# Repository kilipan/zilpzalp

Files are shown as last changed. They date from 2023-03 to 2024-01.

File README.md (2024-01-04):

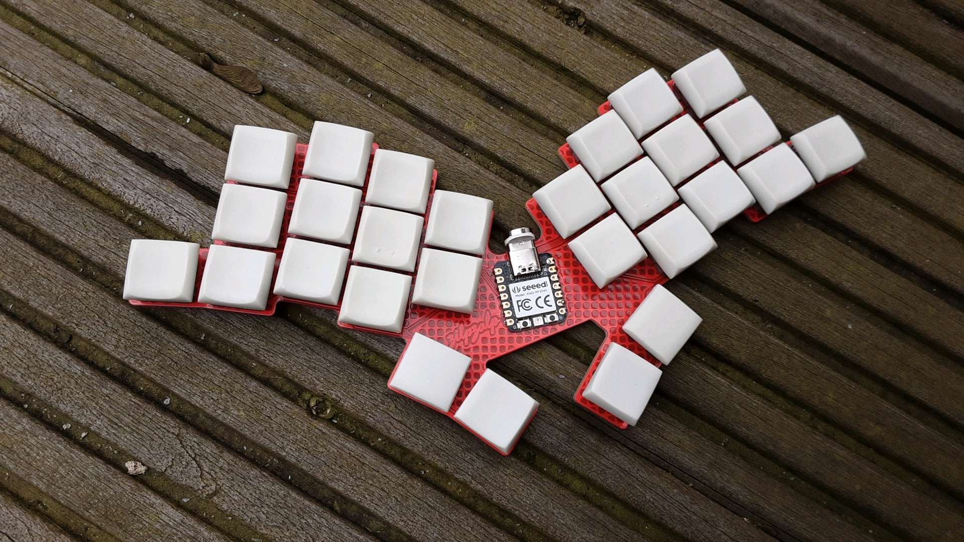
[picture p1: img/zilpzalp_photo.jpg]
zilpzalp


# zilpzalp
A wonky 28-key, column-staggered, unibody-split keyboard made with fantastic FOSS software: [ergogen](https://github.com/ergogen/ergogen) and [KiCad](https://www.kicad.org/).

For buying ready-to-assemble kits, consider [keeb.supply](https://keeb.supply/products/zilpzalp)! They share part of the profits made by selling zilpzalp with me!

Four versions for choc switches are available:
- the choc version with support for optional hotswap sockets and slightly extended edgecuts to acommodate the extra space required by the socket (in the [pcb](https://github.com/kilipan/zilpzalp/tree/main/pcb) directory)
- the cfx version with different spacing, making the zilpzalp almost 1.5 cm smaller horizontally (in the [pcb_cfx_spacing](https://github.com/kilipan/zilpzalp/tree/main/pcb_cfx_spacing) directory)
- the default-spacing solder-only version with tighter edge cuts (in the [pcb_solder_only](https://github.com/kilipan/zilpzalp/tree/main/pcb_solder_only) directory)
- the minimal-choc-spacing solder-only version with the tightest spacing that choc V1 switches allow for (in the [pcb_minimal_choc](https://github.com/kilipan/zilpzalp/tree/main/pcb_minimal_choc) directory)  
  **Note:** You will have to procure minimal-spacing keycaps. I am not aware of any commercial solution. Recommendation: [Philadelphia Minimalist](https://github.com/pseudoku/PseudoMakeMeKeyCapProfiles/blob/master/Philadelphia_Minimalist.scad) by [Pseudoku](https://github.com/pseudoku)

One version for MX, KS-27, and KS-33 switches is available:
- this version has default MX-spacing and features a hybrid switch-footprint for hotswap-only MX and solder-only KS-27/33 (in the [pcb_mx_spacing](https://github.com/kilipan/zilpzalp/tree/main/pcb_mx_spacing) directory)

**Warning:** The solder-only default choc-spacing version has not been tested yet!

Some example keymaps for getting an idea of how zilpzalp may be used can be found in the [`example_keymaps` directory](https://github.com/kilipan/zilpzalp/tree/main/example_keymaps).

## BOM
- 1 pcb
- 1 Seeed XIAO compatible controller, like e.g. [Miao](https://github.com/kilipan/miao)
- 14 sot23 diodes (common cathode)
- optional (for hot swap versions only): 28 hot swap sockets  
  (choc or mx depending on pcb version)
- 28 kailh choc low profile switches
- 28 fitting keycaps (pay special attention here when building the cfx or minimal-spacing version!)

## Firmware
I personally use and recommend [ZMK firmware](https://github.com/kilipan/zmk-config-zilpzalp) which is tested and confirmed-functional for the Seeed XIAO RP2040 and the Seeed XIAO BLE controllers.  
Check out [FAK firmware](https://github.com/semickolon/fak) if you're planning to use the Miao!  
[QMK firmware](https://github.com/kilipan/qmk-config-zilpzalp) for the Seeed XIAO RP2040 is also available.

## Inspiration
- all the fantastic keyboards, knowledge, and help by [GEIST](https://github.com/GEIGEIGEIST/), [Freya](https://linktr.ee/freya_irl), [Bob](https://github.com/GroooveBob), and the wonderful Clacktales keyboard community
- the [hummingbird](https://github.com/PJE66/hummingbird) keyboard and the [rufous](https://github.com/jcmkk3/trochilidae#rufous) variation
- the [aptmak](https://github.com/apsu/aptmak) keymap

<p align="center">

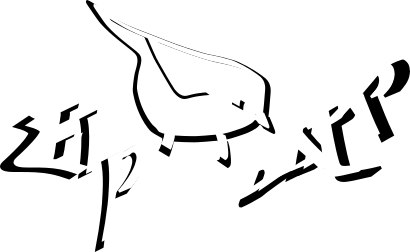
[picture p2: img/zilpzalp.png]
zilpzalp


</p>

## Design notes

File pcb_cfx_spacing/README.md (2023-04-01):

# CFX VERSION
**Warning:** This pcb version uses tighter spacing between switches and **most common keycaps do not fit!**  
  
This pcb was designed for Chosfox's Chocfox (a.k.a. CFX) keycaps' spacing in mind. That means only **square** keycaps with 16.5 mm by 16.5 mm (or smaller) will fit.

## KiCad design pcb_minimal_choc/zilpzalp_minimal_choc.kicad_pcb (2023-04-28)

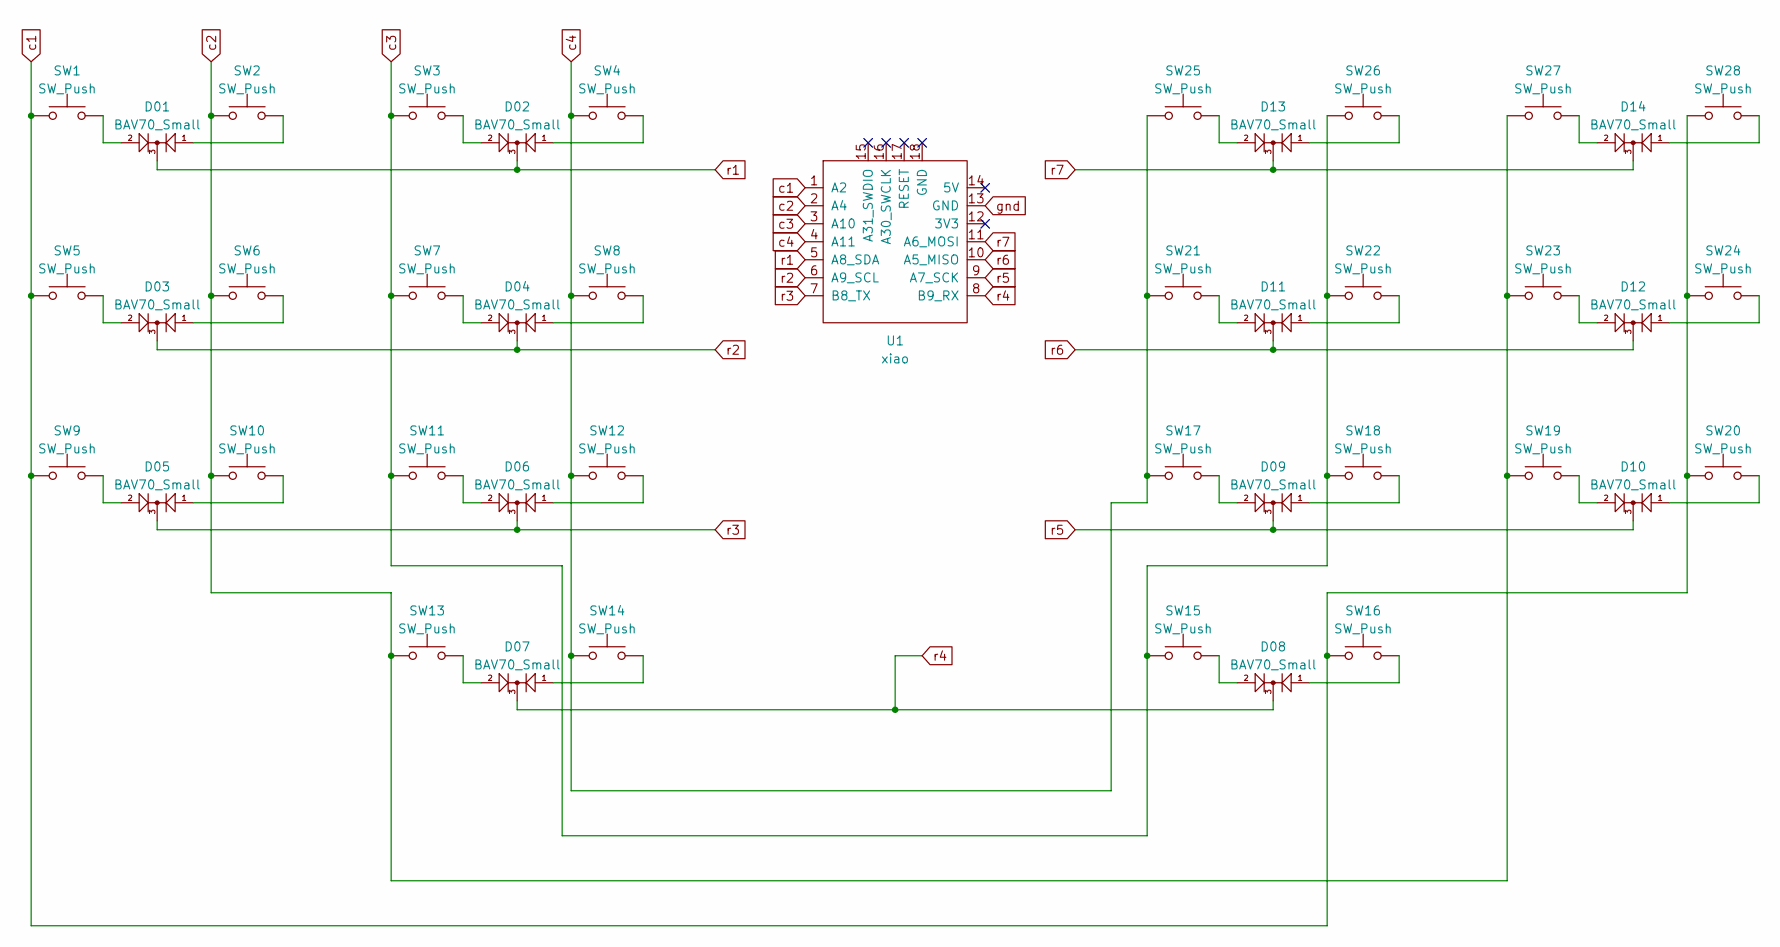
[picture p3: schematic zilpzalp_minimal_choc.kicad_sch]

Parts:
D01, D02, D03, D04, D05, D06, D07, D08, D09, D10, D11, D12, D13, D14: BAV70_Small; SOT-23_Handsoldering
SW1, SW2, SW3, SW4, SW5, SW6, SW7, SW8, SW9, SW10, SW11, SW12, SW13, SW14, SW15, SW16, SW17, SW18, SW19, SW20, SW21, SW22, SW23, SW24, SW25, SW26, SW27, SW28: SW_Push; SW_Kailh-PG1350-1u-NoLED
U1: xiao; xiao-tht

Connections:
unnamed: D01.1 (A1), SW2.2
unnamed: D01.2 (A2), SW1.2
unnamed: D02.1 (A1), SW4.2
unnamed: D02.2 (A2), SW3.2
unnamed: D03.1 (A1), SW6.2
unnamed: D03.2 (A2), SW5.2
unnamed: D04.1 (A1), SW8.2
unnamed: D04.2 (A2), SW7.2
unnamed: D05.1 (A1), SW10.2
unnamed: D05.2 (A2), SW9.2
unnamed: D06.1 (A1), SW12.2
unnamed: D06.2 (A2), SW11.2
unnamed: D07.1 (A1), SW14.2
unnamed: D07.2 (A2), SW13.2
unnamed: D08.1 (A1), SW16.2
unnamed: D08.2 (A2), SW15.2
unnamed: D09.1 (A1), SW18.2
unnamed: D09.2 (A2), SW17.2
unnamed: D10.1 (A1), SW20.2
unnamed: D10.2 (A2), SW19.2
unnamed: D11.1 (A1), SW22.2
unnamed: D11.2 (A2), SW21.2
unnamed: D12.1 (A1), SW24.2
unnamed: D12.2 (A2), SW23.2
unnamed: D13.1 (A1), SW26.2
unnamed: D13.2 (A2), SW25.2
unnamed: D14.1 (A1), SW28.2
unnamed: D14.2 (A2), SW27.2
c1: SW1.1, SW5.1, SW9.1, SW16.1, SW20.1, SW24.1, SW28.1, U1.1 (A2)
c2: SW2.1, SW6.1, SW10.1, SW13.1, SW19.1, SW23.1, SW27.1, U1.2 (A4)
c3: SW3.1, SW7.1, SW11.1, SW15.1, SW18.1, SW22.1, SW26.1, U1.3 (A10)
c4: SW4.1, SW8.1, SW12.1, SW14.1, SW17.1, SW21.1, SW25.1, U1.4 (A11)
gnd: U1.13 (GND)
r1: D01.3 (K), D02.3 (K), U1.5 (A8_SDA)
r2: D03.3 (K), D04.3 (K), U1.6 (A9_SCL)
r3: D05.3 (K), D06.3 (K), U1.7 (B8_TX)
r4: D07.3 (K), D08.3 (K), U1.8 (B9_RX)
r5: D09.3 (K), D10.3 (K), U1.9 (A7_SCK)
r6: D11.3 (K), D12.3 (K), U1.10 (A5_MISO)
r7: D13.3 (K), D14.3 (K), U1.11 (A6_MOSI)

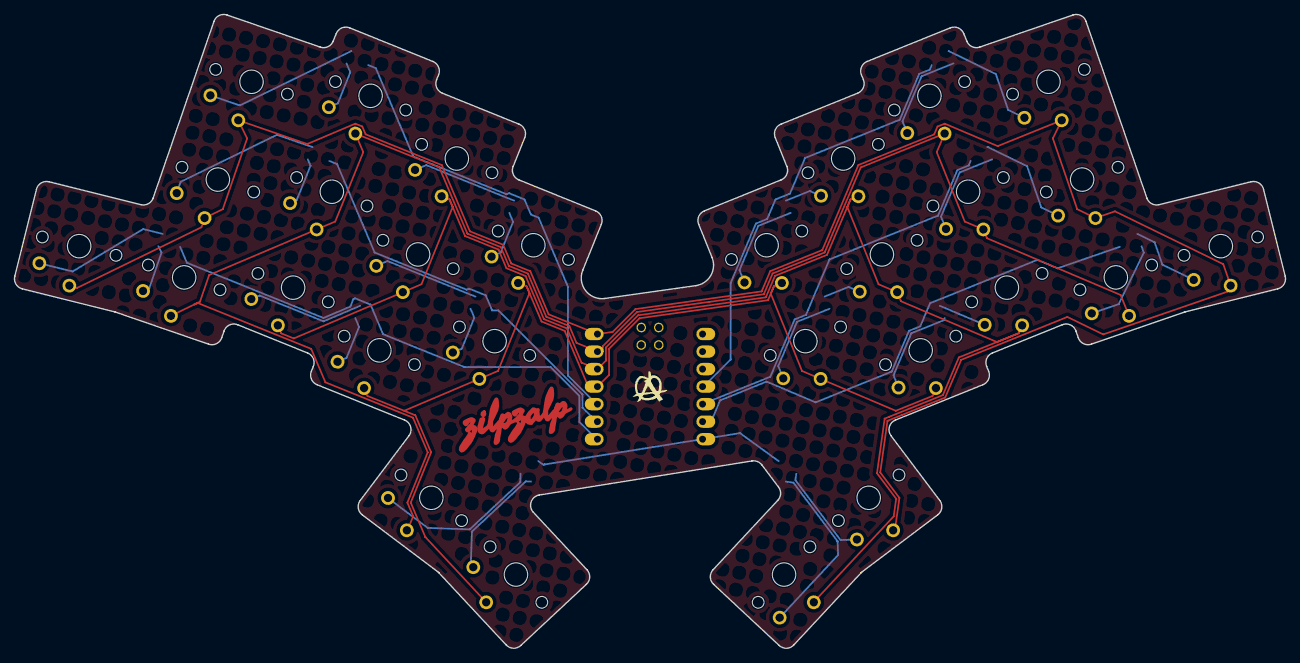
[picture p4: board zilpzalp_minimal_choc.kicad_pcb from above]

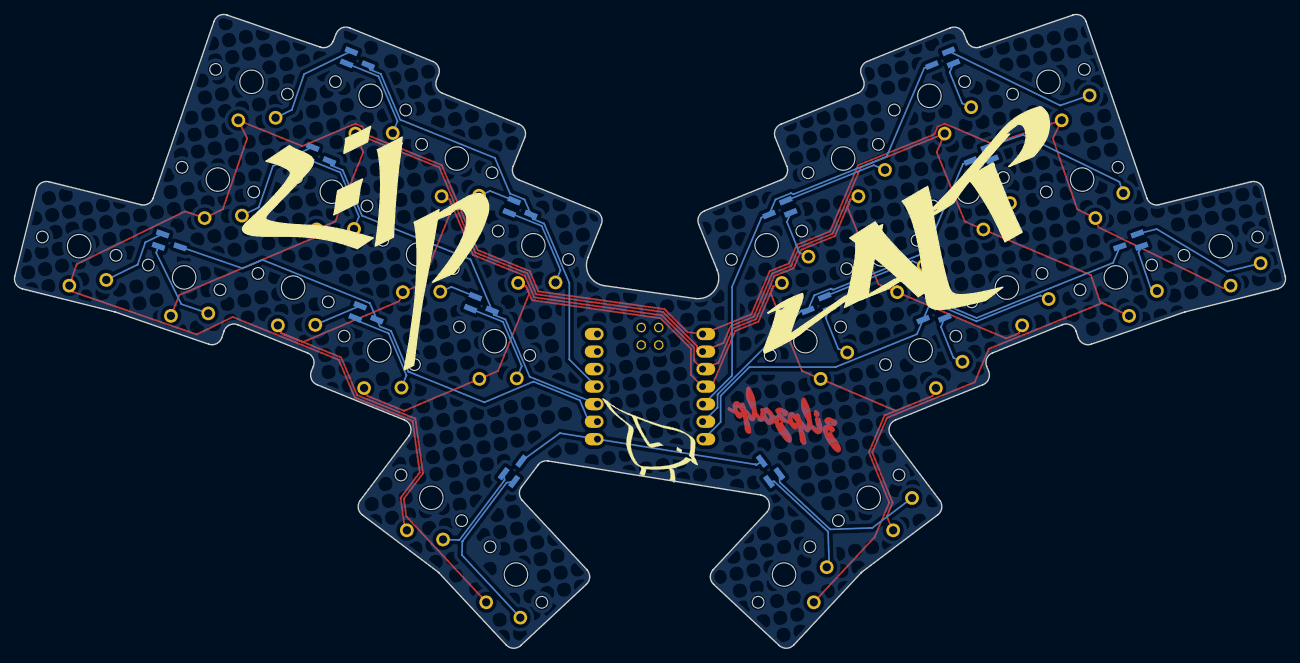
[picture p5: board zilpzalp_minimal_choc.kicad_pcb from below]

Board: 2 copper layers, 184.3 x 91.9 mm, 43 parts (14 on the bottom side), 39 nets.

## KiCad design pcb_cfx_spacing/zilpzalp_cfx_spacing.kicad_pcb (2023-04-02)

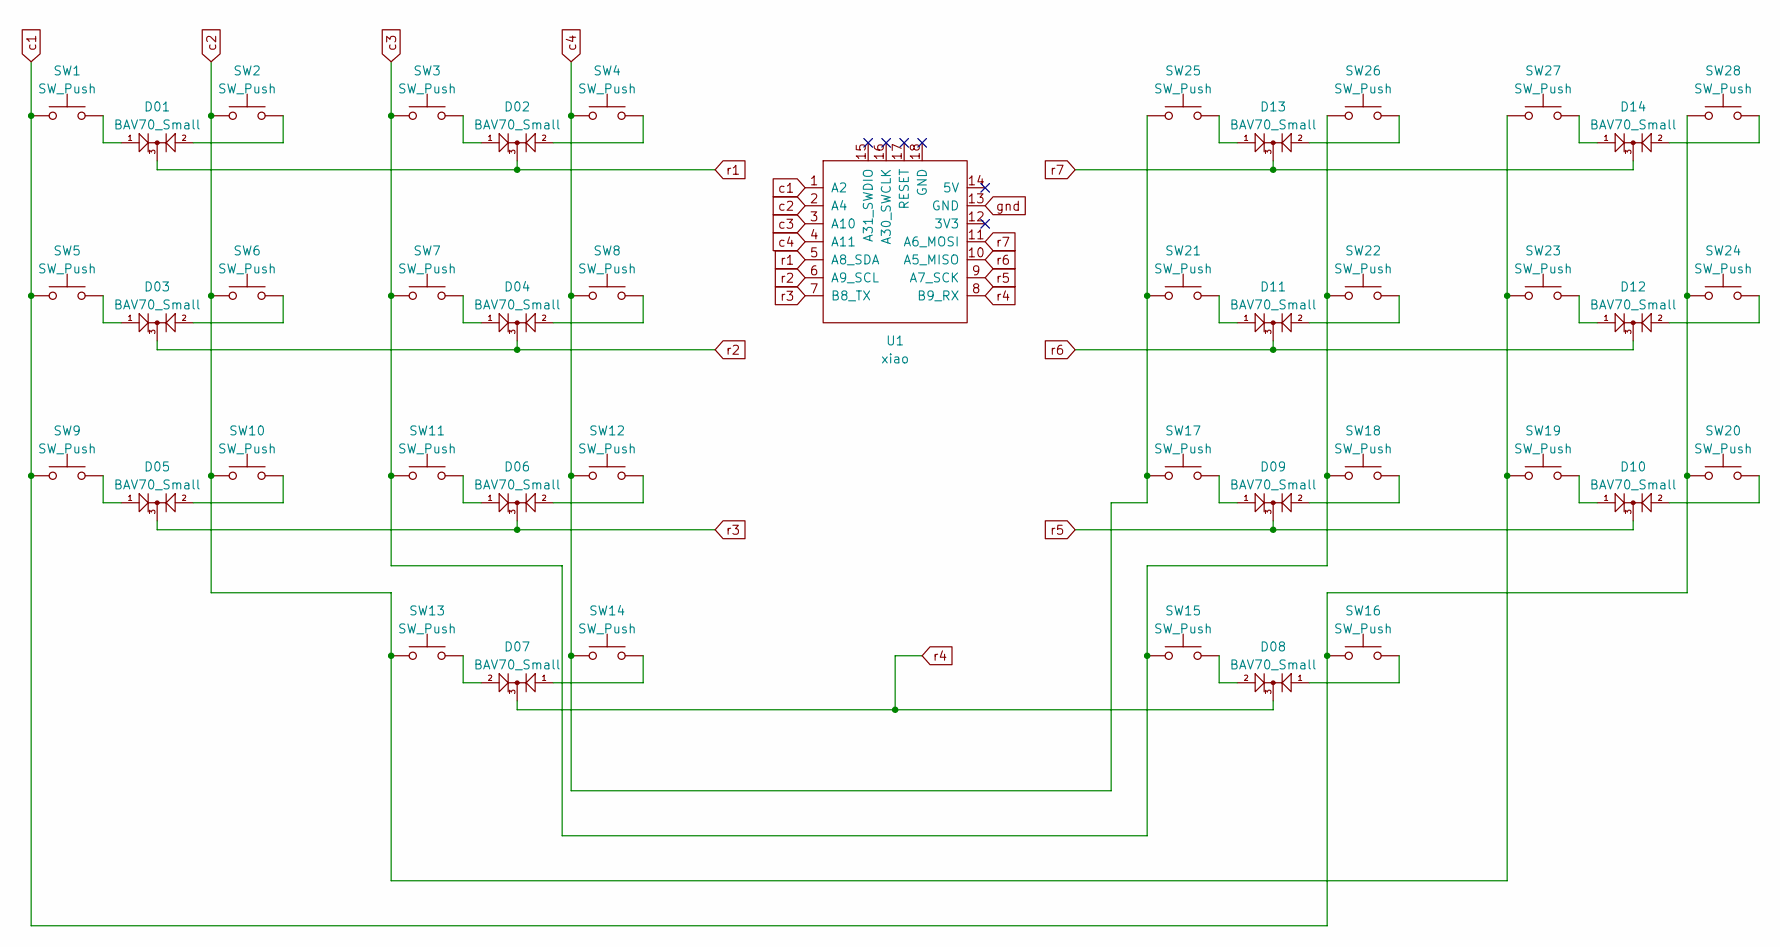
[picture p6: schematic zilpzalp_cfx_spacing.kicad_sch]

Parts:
D01, D02, D03, D04, D05, D06, D07, D08, D09, D10, D11, D12, D13, D14: BAV70_Small; SOT-23_Handsoldering
SW1, SW2, SW3, SW4, SW5, SW6, SW7, SW8, SW9, SW10, SW11, SW12, SW13, SW14, SW15, SW16, SW17, SW18, SW19, SW20, SW21, SW22, SW23, SW24, SW25, SW26, SW27, SW28: SW_Push; SW_Kailh_choc_hs_plus_solder_no_silk
U1: xiao; xiao-tht

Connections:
unnamed: D01.1 (A1), SW1.2
unnamed: D01.2 (A2), SW2.2
unnamed: D02.1 (A1), SW3.2
unnamed: D02.2 (A2), SW4.2
unnamed: D03.1 (A1), SW5.2
unnamed: D03.2 (A2), SW6.2
unnamed: D04.1 (A1), SW7.2
unnamed: D04.2 (A2), SW8.2
unnamed: D05.1 (A1), SW9.2
unnamed: D05.2 (A2), SW10.2
unnamed: D06.1 (A1), SW11.2
unnamed: D06.2 (A2), SW12.2
unnamed: D07.1 (A1), SW14.2
unnamed: D07.2 (A2), SW13.2
unnamed: D08.1 (A1), SW16.2
unnamed: D08.2 (A2), SW15.2
unnamed: D09.1 (A1), SW17.2
unnamed: D09.2 (A2), SW18.2
unnamed: D10.1 (A1), SW19.2
unnamed: D10.2 (A2), SW20.2
unnamed: D11.1 (A1), SW21.2
unnamed: D11.2 (A2), SW22.2
unnamed: D12.1 (A1), SW23.2
unnamed: D12.2 (A2), SW24.2
unnamed: D13.1 (A1), SW25.2
unnamed: D13.2 (A2), SW26.2
unnamed: D14.1 (A1), SW27.2
unnamed: D14.2 (A2), SW28.2
c1: SW1.1, SW5.1, SW9.1, SW16.1, SW20.1, SW24.1, SW28.1, U1.1 (A2)
c2: SW2.1, SW6.1, SW10.1, SW13.1, SW19.1, SW23.1, SW27.1, U1.2 (A4)
c3: SW3.1, SW7.1, SW11.1, SW15.1, SW18.1, SW22.1, SW26.1, U1.3 (A10)
c4: SW4.1, SW8.1, SW12.1, SW14.1, SW17.1, SW21.1, SW25.1, U1.4 (A11)
gnd: U1.13 (GND)
r1: D01.3 (K), D02.3 (K), U1.5 (A8_SDA)
r2: D03.3 (K), D04.3 (K), U1.6 (A9_SCL)
r3: D05.3 (K), D06.3 (K), U1.7 (B8_TX)
r4: D07.3 (K), D08.3 (K), U1.8 (B9_RX)
r5: D09.3 (K), D10.3 (K), U1.9 (A7_SCK)
r6: D11.3 (K), D12.3 (K), U1.10 (A5_MISO)
r7: D13.3 (K), D14.3 (K), U1.11 (A6_MOSI)

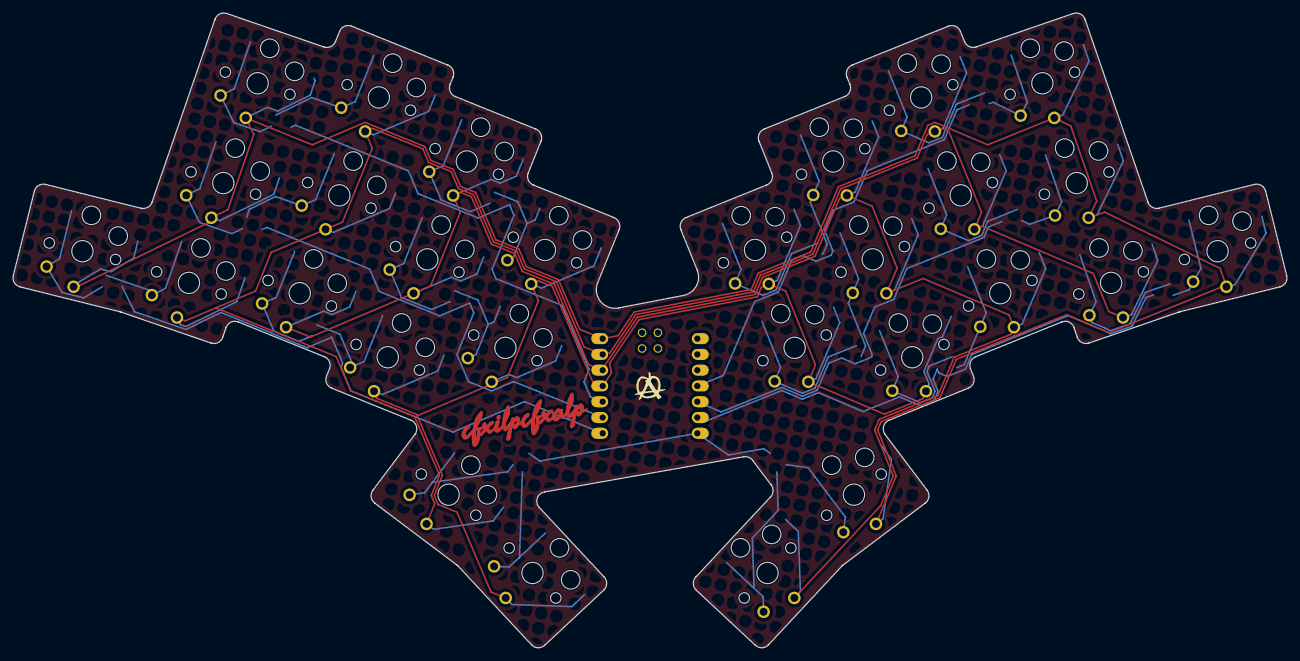
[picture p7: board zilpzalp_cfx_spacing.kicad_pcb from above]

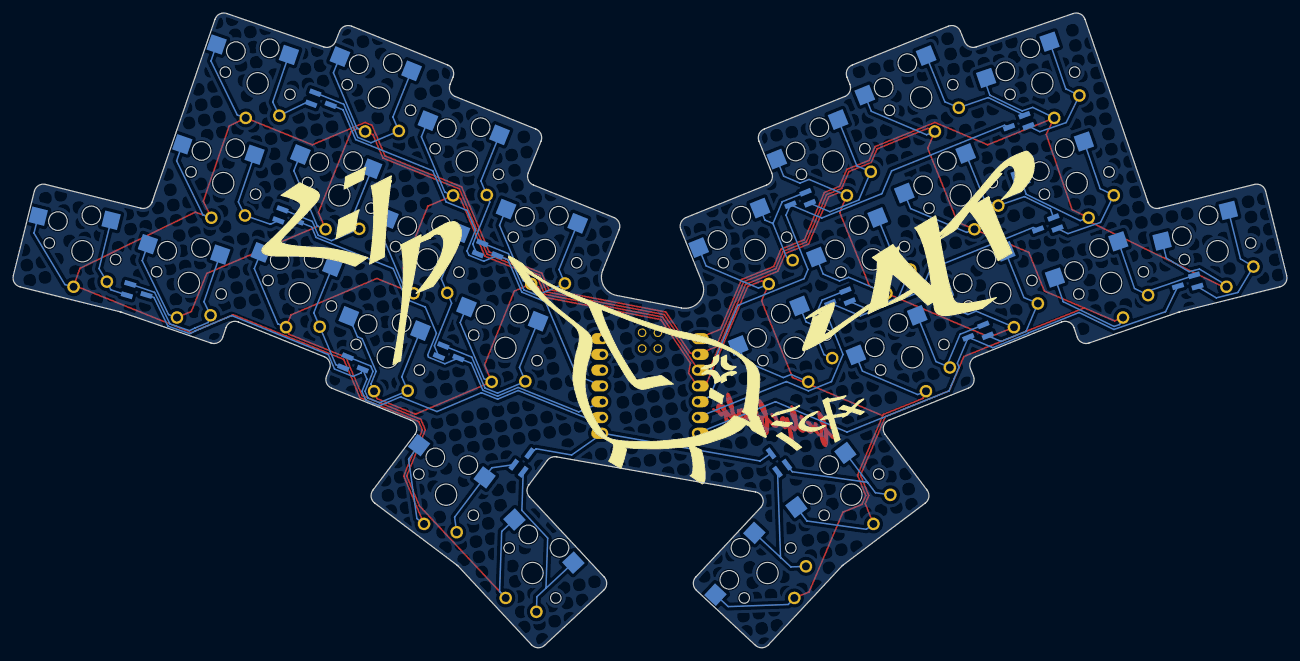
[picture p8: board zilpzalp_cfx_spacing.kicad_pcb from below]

Board: 2 copper layers, 205.1 x 102.2 mm, 43 parts (14 on the bottom side), 39 nets.

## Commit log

2023-03-09 add pcb files
    [zilpzalp.kicad_pcb, zilpzalp.kicad_sch]
2023-03-10 add ground fill and silk
2023-03-10 change xiao footprint, silk slightly smaller
    [zilpzalp.kicad_sch]
2023-03-10 update readme, make all pcb layers visible by default
2023-03-10 add gerbers
2023-03-12 add solder-only version
    [zilpzalp_solder_only.kicad_sch]
2023-04-01 add cfx spacing version
    [zilpzalp_cfx_spacing.kicad_pcb, zilpzalp_cfx_spacing.kicad_sch, zilpzalp_solder_only.kicad_sch]
2023-04-01 add warning to cfx spacing pcb directory
2023-04-02 beautify routing slightly
    [zilpzalp_cfx_spacing.kicad_pcb]
2023-04-28 add minimal-spacing version
    [zilpzalp_minimal_choc.kicad_pcb, zilpzalp_minimal_choc.kicad_sch]
2023-05-28 add mx/ks version
    [zilpzalp_mx_spacing.kicad_sch]
2023-05-29 add mounting holes
    [zilpzalp_mx_spacing.kicad_sch]
2023-05-29 add top & bottom plate files
    [zilpzalp_mx_bottom_plate.kicad_pcb, zilpzalp_mx_bottom_plate.kicad_sch, zilpzalp_mx_switch_plate.kicad_pcb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]
